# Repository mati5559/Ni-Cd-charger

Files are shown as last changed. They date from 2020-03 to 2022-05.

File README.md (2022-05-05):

# Ni-Cd charger
Charger for 24V (10 s) NiCd battery

# Description
This charger was designed to charge 24V NiCd battery with current about 1,2A. It uses continous current method and delta V detection. 

Schematic contains DC-DC step up converter, microcontroller, current source.
Step up converter generates higher voltage than input voltage and limits current. It is very efficient (about 85%).
Current source limits short circuit current and charging current when battery voltage is lower than input voltage. It generates a lot of heat, so it have big radiator and temperature sensor to prevent overheat. In case of overheat charging will be interrupted  and error LED will blink. After cooling down charging will be resumed automatically. Current source works only for a while at the beginning of charging and when circuit is shorted. Most of the time it is turned off and do not generate heat. 
Microcontroller controls charging process, turns on and off step up converter and current source, measures voltages, tepmerature etc. 

You can regulate charging current with R13 potentiometer, short circuit current with R6 potentiometer (it must be greather than charging current) and maximum output voltage with R16 potentiometer. 

Other parameters can be modified in config.hpp file before programming Attiny13. 

# How to use it
1. Connect power supply to X1 screw clamp (20V 4A).
2. Connect battery to X2 screw clamp and temperature sensor to pin 3 and 4 of JP1. (short pin 3 and 4 of JP1 if your battery do not have temperature sensor)
3. LED1 should light up.
4. Charging is ended when both LEDs are not lighting.

If LED2 is blinking it seems that over temperature protection was activated. You should wait a while to cool down. Charger will automatically turn on.
If LED2 lights constantly it seems that something went wrong (for example battery was disconnected, is dead or charger is broken). You should turn off power supply for a while, make sure that all is connected properly and turn on power supply. 

GNU GPL license
Source code and hardware is open and free of charge for everyone.

Author is not responsible for any damages made by this device.
You make and use it at your own risk.

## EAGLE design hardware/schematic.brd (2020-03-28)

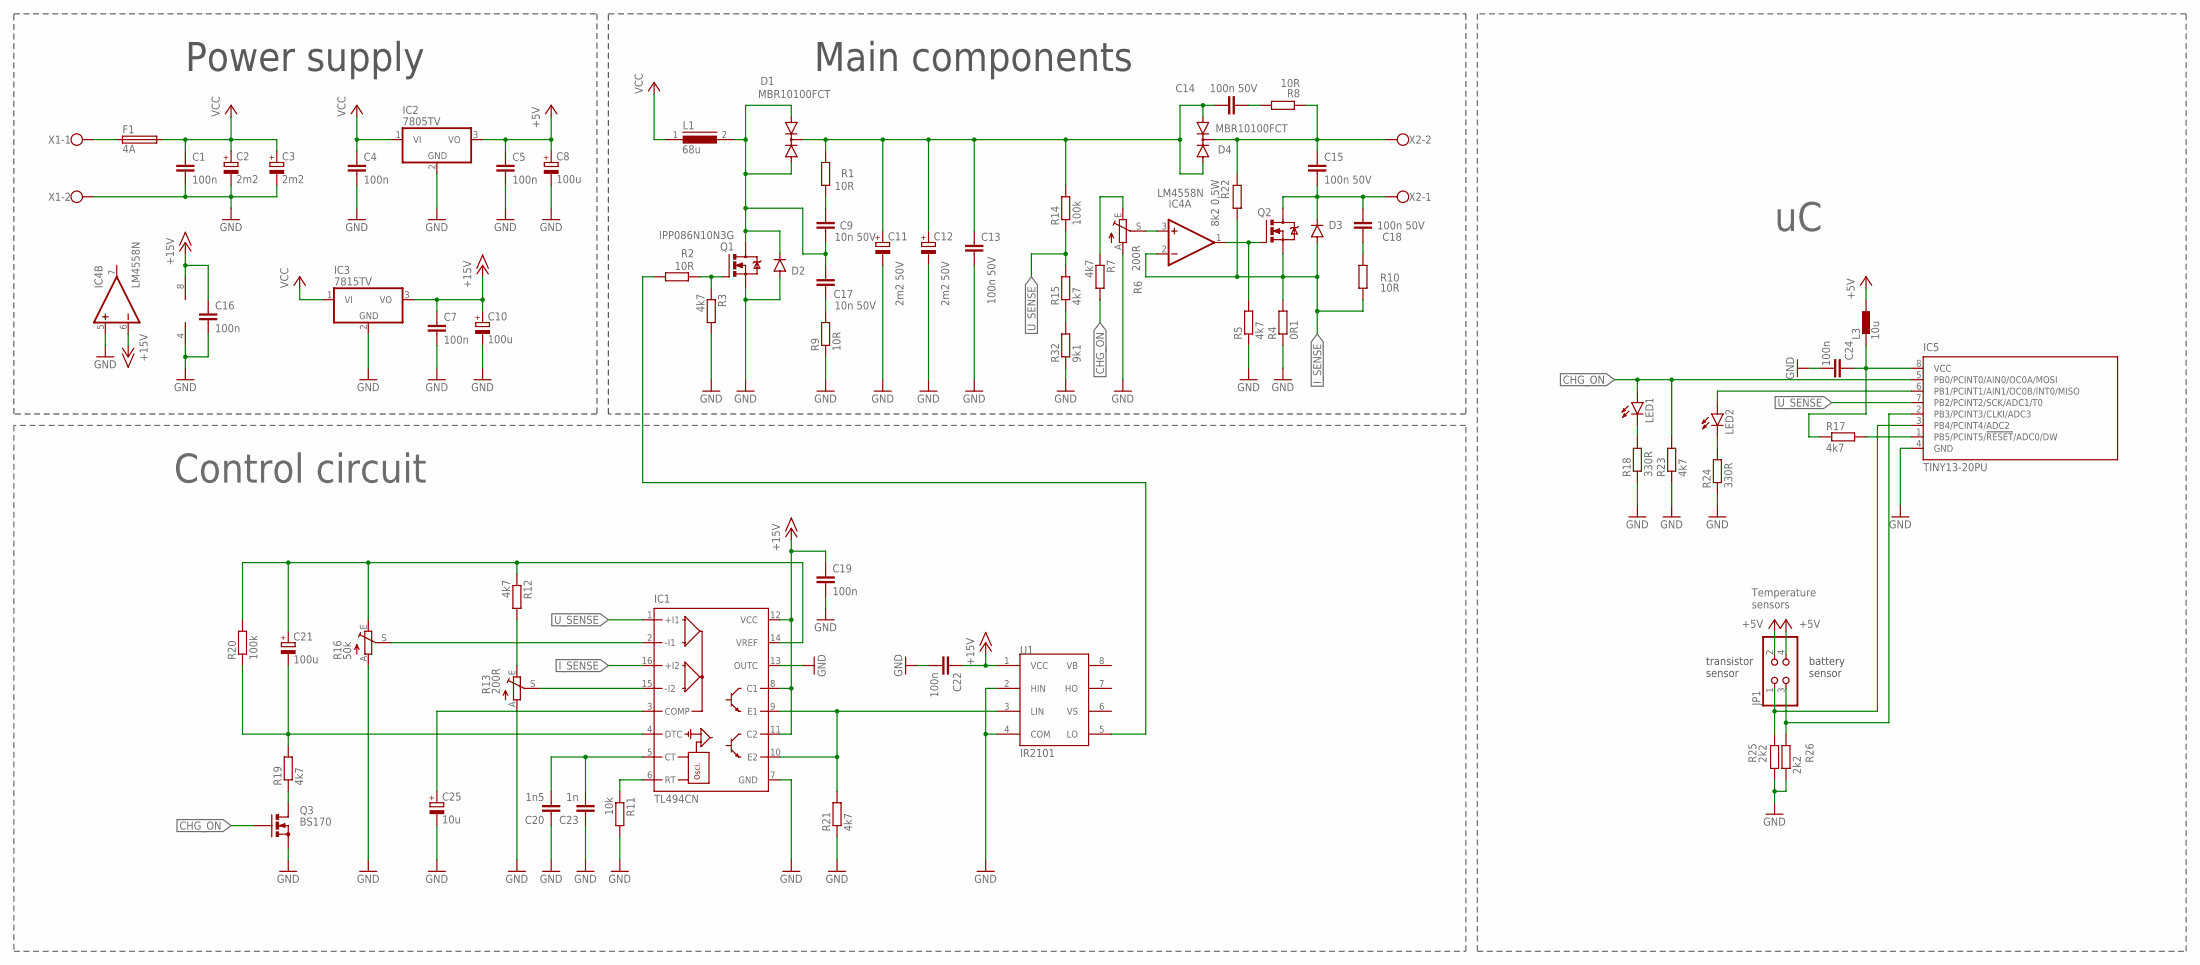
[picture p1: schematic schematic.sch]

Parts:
C1, C4, C5, C7, C16, C19, C22, C24: 100n; C2.5-2
C2, C3: 2m2; E7,5-16
C8, C10, C21: 100u; E3,5-8
C9, C17: 10n 50V; C2.5-2
C11, C12: 2m2 50V; E7,5-18
C13, C14, C15, C18: 100n 50V; C2.5-2
C20: 1n5; C2.5-2
C23: 1n; C2.5-2
C25: 10u; E2,5-5
D1, D4: MBR10100FCT; TO220ABS
D2, D3: 1N4933; DO41-10
F1: 4A; SH22
IC1: TL494CN; DIL16
IC2: 7805TV; TO220V
IC3: 7815TV; TO220V
IC4: LM4558N; DIL08
IC5: TINY13-20PU; DIL08
JP1: PINHD-2X2; 2X02
L1: 68u; SFT1240
L3: 10u; BL01RN1A
LED1, LED2: LED5MM
Q1: IPP086N10N3G; TO220BV
Q2: IRF520; TO220BV
Q3: BS170; SOT54E
R1, R2, R8, R9, R10: 10R; 0204/7
R3, R5, R7, R12, R15, R17, R19, R21, R23: 4k7; 0204/7
R4: 0R1; 0204/5
R6, R13: 200R; B64Y
R11: 10k; 0204/7
R14, R20: 100k; 0204/7
R16: 50k; B64W
R18, R24: 330R; 0204/7
R22: 8k2 0,5W; 0204/7
R25, R26: 2k2; 0204/7
R32: 9k1; 0204/7
U1: IR2101; DIL08
X1, X2: W237-102

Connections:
+5V: C5.1, C8.+, IC2.3 (VO), JP1.2, JP1.4, L3.2
+15V: C7.1, C10.+, C16.1, C19.1, C22.1, IC1.8 (C1), IC1.11 (C2), IC1.12 (VCC), IC3.3 (VO), IC4.6 (-IN), IC4.8 (V+), U1.1 (VCC)
CHG_ON: IC5.5 (PB0/PCINT0/AIN0/OC0A/MOSI), LED1.A, Q3.G, R7.2, R23.2
GND: C1.2, C2.-, C3.-, C4.2, C5.2, C7.2, C8.-, C10.-, C11.-, C12.-, C13.2, C16.2, C19.2, C20.1, C22.2, C23.1, C24.2, C25.-, D2.A, IC1.7 (GND), IC1.13 (OUTC), IC2.2 (GND), IC3.2 (GND), IC4.4 (V-), IC4.5 (+IN), IC5.4 (GND), Q1.S, Q3.S, R3.2, R4.1, R5.1, R6.A, R9.1, R11.2, R13.A, R16.A, R18.1, R21.1, R23.1, R24.1, R25.1, R26.1, R32.1, U1.2 (HIN), U1.4 (COM), X1.2
I_SENSE: D3.A, IC1.16 (+I2), IC4.2 (-IN), Q2.S, R4.2, R10.2, R22.2
unnamed: F1.1, X1.1
unnamed: C18.2, R10.1
unnamed: C11.+, C12.+, C13.1, C14.2, D1.C, D4.A1, D4.A2, R1.2, R14.2
unnamed: Q1.G, R2.1, R3.1
unnamed: C17.2, R9.2
unnamed: IC1.15 (-I2), R13.S
unnamed: C15.2, C18.1, D3.C, Q2.D, X2.1
unnamed: IC4.1 (OUT), Q2.G, R5.2
unnamed: R6.E, R7.1
unnamed: IC4.3 (+IN), R6.S
unnamed: C14.1, R8.2
unnamed: C15.1, D4.C, R8.1, R22.1, X2.2
unnamed: C9.2, C17.1, D1.A1, D1.A2, D2.C, L1.2, Q1.D
unnamed: C9.1, R1.1
unnamed: C20.2, C23.2, IC1.5 (CT)
unnamed: IC1.6 (RT), R11.1
unnamed: R12.2, R13.E
unnamed: C21.+, IC1.14 (VREF), R12.1, R16.E, R20.2
unnamed: IC1.2 (-I1), R16.S
unnamed: LED2.K (C), R24.2
unnamed: IC5.1 (PB5/PCINT5/!RESET!/ADC0/DW), R17.2
unnamed: Q3.D, R19.1
unnamed: C21.-, IC1.4 (DTC), R19.2, R20.1
unnamed: IC1.9 (E1), IC1.10 (E2), R21.2, U1.3 (LIN)
unnamed: R2.2, U1.5 (LO)
unnamed: LED1.K (C), R18.2
unnamed: C25.+, IC1.3 (COMP)
unnamed: C24.1, IC5.8 (VCC), L3.1, R17.1
unnamed: IC5.6 (PB1/PCINT1/AIN1/OC0B/INT0/MISO), LED2.A
unnamed: IC5.3 (PB4/PCINT4/ADC2), JP1.1, R25.2
unnamed: IC5.2 (PB3/PCINT3/CLKI/ADC3), JP1.3, R26.2
unnamed: R15.1, R32.2
U_SENSE: IC1.1 (+I1), IC5.7 (PB2/PCINT2/SCK/ADC1/T0), R14.1, R15.2
VCC: C1.1, C2.+, C3.+, C4.1, F1.2, IC2.1 (VI), IC3.1 (VI), L1.1

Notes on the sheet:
Power supply
Main components
transistor sensor
battery sensor
Temperature sensors
Control circuit

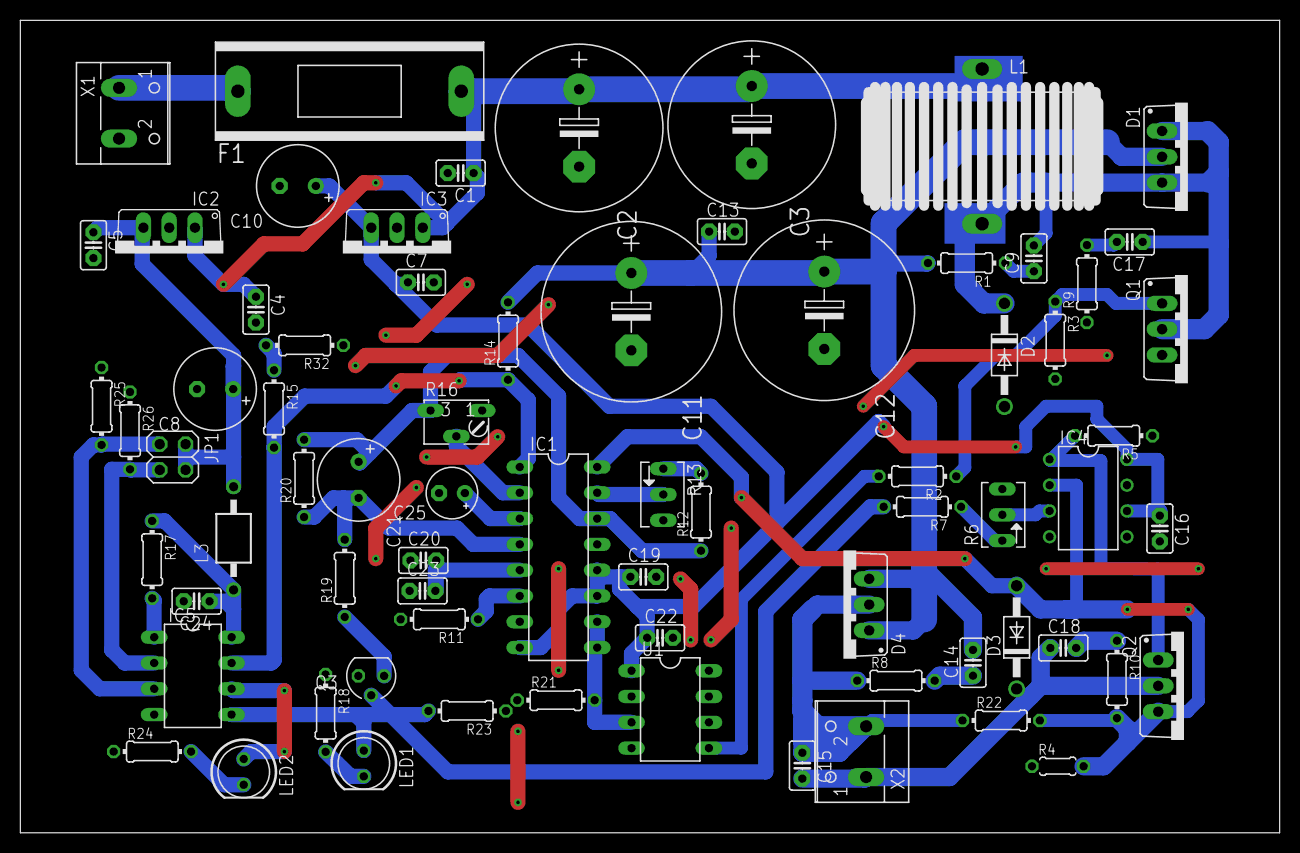
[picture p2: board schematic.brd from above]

Board: 2 copper layers, 124.0 x 80.0 mm, 72 parts (0 on the bottom side), 39 nets.

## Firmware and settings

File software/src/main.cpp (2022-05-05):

/*
 *  main.cpp
 *
 *  Created on: 8 mar 2020
 *
 *  Author: Mateusz Dąbrowski (mati5559)
 *  Github: https://github.com/mati5559
 *
 *  GNU GPL license
 *  Source code and hardware is open and free of charge for everyone.
 *
 *  Author is not responsible for any damages made by this device.
 *  You use it at your own risk.
 */





// Include requied libraries
#include <avr/wdt.h>
#include <avr/io.h>
#include <util/delay.h>

#include "adc.hpp"
#include "config.hpp"


// Define some values to make code more transparent
#define CHG_OFF PORTB &= 0b11111110
#define CHG_ON PORTB |= 0b00000001
#define ERR_DIODE_ON PORTB |= 0b00000010
#define ERR_DIODE_OFF PORTB &= 0b11111101

int vol_ath = 0;

int main()
{
	// reset watchdog
	bool error = false;
	if(MCUSR & 0b00001000) error = true;
	MCUSR = 0x00;
	wdt_disable();



	// wait for voltage stabilization and init everything
	_delay_ms(1000);
	adc::init();

	// watchdog enable (1s)
	wdt_enable(WDTO_1S);

	// set pin mode
	DDRB = 0b00000011;
	CHG_OFF;

	// Wait for battery connection
	while(READ_BATTERY_TEMP < 20)
	{
		wdt_reset();
	}


	// Wait 10s if uC reset from watchdog
	// it prevents burning the device
	if(error)
	{
		error = false;
		for(int a = 0; a<20; a++)
		{
			wdt_reset();
			_delay_ms(500);
		}
	}

	// start charging
	wdt_reset();
	_delay_ms(500);
	CHG_ON;

	int thread_1 = 0;

	while(1)
	{
		// reset watchdog
		wdt_reset();


		// count loop iterations
		thread_1++;


		// measure actual battery voltage
		int vol_actual = READ_BATTERY_VOLTAGE;


		// over voltage protection - turn off charger and light up error diode when voltage is too high
		if(vol_actual > OVP_VOL)
		{
			CHG_OFF;
			ERR_DIODE_ON;
			wdt_disable();
			return 0;
		}


		// check if measured voltage is higher than voltage measured a while ago
		if(vol_actual > vol_ath)
		{
			vol_ath = vol_actual;
		}


		// detect if battery voltage decreased
		if((vol_ath - vol_actual) > DELTA_V)
		{
			// turn off charger
			CHG_OFF;
			wdt_disable();
			return 0;
		}

		// instructions that are not critical and can be done every 20 loop iterations
		if(thread_1 > 20)
		{
			thread_1 = 0;

			// checking if battery temperature is too high
			if(READ_BATTERY_TEMP > MAX_BATTERY_TMP)
			{
				// turn off charger
				CHG_OFF;

				// blink error diode
				while(READ_BATTERY_TEMP > (MAX_BATTERY_TMP - BATTERY_TMP_HYSTERESIS))
				{
					ERR_DIODE_ON;

					wdt_reset();
					_delay_ms(500);
					wdt_reset();
					_delay_ms(500);


					ERR_DIODE_OFF;


					wdt_reset();
					_delay_ms(500);
					wdt_reset();
					_delay_ms(500);
				}
				vol_ath = 0;
				CHG_ON;
			}


			// checking if transistor temperature is too high
			if(READ_TRANSISTOR_TEMP > MAX_TRANSISTOR_TMP)
			{
				// turn off charger
				CHG_OFF;

				// blink error diode
				while(READ_TRANSISTOR_TEMP > (MAX_TRANSISTOR_TMP - TRANSISTOR_TMP_HYSTERESIS))
				{
					ERR_DIODE_ON;

					wdt_reset();
					_delay_ms(500);
					wdt_reset();
					_delay_ms(500);


					ERR_DIODE_OFF;


					wdt_reset();
					_delay_ms(500);
					wdt_reset();
					_delay_ms(500);
				}
				vol_ath = 0;
				CHG_ON;
			}
		}
	}
}

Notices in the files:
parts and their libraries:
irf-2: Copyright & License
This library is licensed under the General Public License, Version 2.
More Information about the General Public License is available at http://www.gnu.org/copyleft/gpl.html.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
